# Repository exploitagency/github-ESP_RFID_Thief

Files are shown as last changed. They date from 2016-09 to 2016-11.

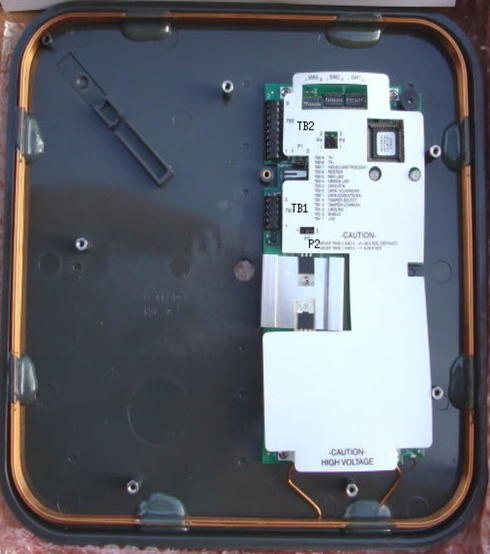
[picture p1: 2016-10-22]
Reference Material/Schematic/5375.jpg

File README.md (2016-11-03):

# ESP_RFID_Thief
Port/Remix by Corey Harding from http://www.LegacySecurityGroup.com<br><br>
This is a port/remix of the Tastic RFID Thief to the Adafruit Feather HUZZAH, an ESP12E chip from the ESP8266 family.  It adds WiFi capability and makes the build nearly plug and play.  There is no SD card as there is a File System library FS.h being utilized and the board has an integrated battery and charging circuit along with WiFi.  One of the benefits of adding WiFi is that now you can remotely view your captures from any standard browser either through the built in access point or by having the ESP_RFID_Thief connect to an existing WiFi network/WiFi-cellular hot spot.  The ESP_RFID_Thief can now play a larger role during penetration testing in a Red Team scenario.  One team member can walk around with the device capturing tags or plant the device while other team members view the capture log.  This way the captured tags can be cloned off site and used by another team member walking in or sent via a network to a tag emulator that the field team member is carrying to avoid looking suspicious by not making the field team member view the logs and manually clone/emulate the card.

<br>
<b>Software used:</b><br>
Arduino IDE: Arduino IDE 1.6.11<br>
Board Manager/Libraries: esp8266 by ESP8266 Community version 2.3.0<br>
<br>
<b>Parts list:</b><br>
HID MaxiProx 5375<br>
Adafruit Feather HUZZAH<br>
2000mah 3.7V Adafruit LiPo Battery<br>
8xAA Battery Holder in Series(12V)<br>
Wire<br>
Solder and Iron<br><br>
<b>Construction:</b><br>
Set voltage jumper on 5375 to 12V.<br>
Optionally disable the beeper(SW1-4).<br>
Insert and screw down red wire from 12V Battery Pack to Positive(+) terminal on the 5375.<br>
Insert and screw down black wire from 12V Battery Pack to Negative(-) terminal on the 5375.<br>
Solder green wire from Data0(Data) to Pin 4 on Feather HUZZAH.<br>
Solder white wire from Data1(Clock) to Pin 5 on Feather HUZZAH.<br>
Solder a wire from GND on the Feather HUZZAH to the GND on the 5375.(Do NOT do the same for Positive)<br>
Attach Lipo Battery to Feather HUZZAH.<br>
Warning: The GPIO Pins on the Feather Huzzah are not supposed to be 5v tolerant(they operate at 3.3v) but this setup has been working fine for me on a breadboard with the 5375 reader powered by 8xAA Batteries. It is recommended to use a level shifter between the Data0/Data1 lines coming from the 5375 and Pins 4/5 on the Feather Huzzah.<br>

<b>Program:</b><br>
Optionally set the ssid and password of the access point being created by the Feather HUZZAH in the sketch source code(.ino file) as well as some other variables such as hidden ssid or IP address.  Or you can even edit the source to make it connect directly to your own network as a client vs being set up as an access point.  I made it easy to set in the source.<br>
Open Current Version Arduino IDE and Install the Library and Board via Board Manager using this link:<br>http://arduino.esp8266.com/stable/package_esp8266com_index.json <br>
Setup the proper board.<br>
Load sketch.<br>
Program.<br>

<b>Access:</b><br>
The Feather HUZZAH has created its own Access Point named "Exploit".<br>
By default the ssid is hidden.<br>
Connect to SSID: "Exploit" WPA2-PASSWORD: "DotAgency"<br>
Wait 90 seconds... while the SPIFFS file system is formatted for the first time.<br>
Open a web browser and connect to the IP address.  Default is http://192.168.1.1 <br>
You can now start scanning cards and view your captures at /log<br>

<b>LEGAL:</b><br>
Obey any international, federal, state, or local laws in your area.<br>
I ported/remixed the Tastic RFID Thief to the Feather HUZZAH for the purpose of proof of concept and legal white hat penetration testing.<br>
I can not and will not be held responsible for the use or misuse of this device.  It is solely up to you to make your own decisions.<br>

That was easy, huh?

Special thanks to Bishop Fox for releasing the original Tastic RFID Thief.<br>
Without them I wouldn't have had the inspiration or motivation to create a tool like this, let alone the code for decoding the Wiegand data.<br>
I hope this build inspires other people to port and remix more projects from the Arduino family over to the ESP8266 devices.<br>

Stay Legal!<br>
-Exploit.Agency

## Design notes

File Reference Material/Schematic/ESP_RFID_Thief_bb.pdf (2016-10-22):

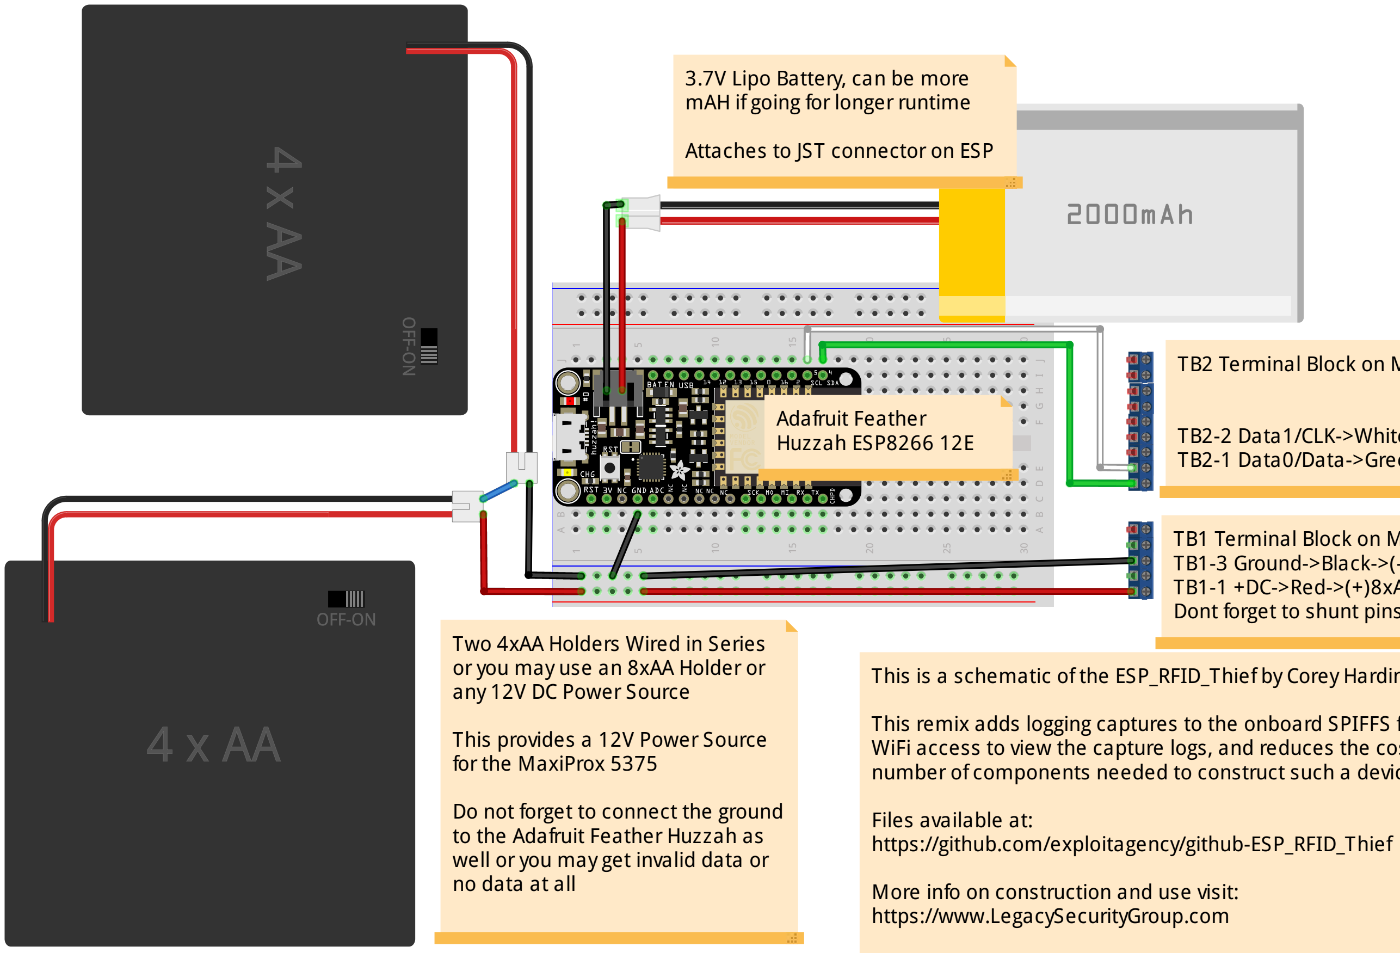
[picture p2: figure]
Two 4xAA Holders Wired in Series or you may use an 8xAA Holder or any 12V DC Power Source; This provides a 12V Power Source forthe MaxiProx 5375; Do not forget to connect the ground to the Adafruit Feather Huzzah as well or you may get invalid data or no data at all; Adafruit Feather Huzzah ESP8266 12E; 3.7V Lipo Battery, can be more mAH if going forlongerruntime; Attaches to JST connector on ESP; Files available at: https://github.com/exploitagency/github-ESP_RFID_Thief; https://www.LegacySecurityGroup.com
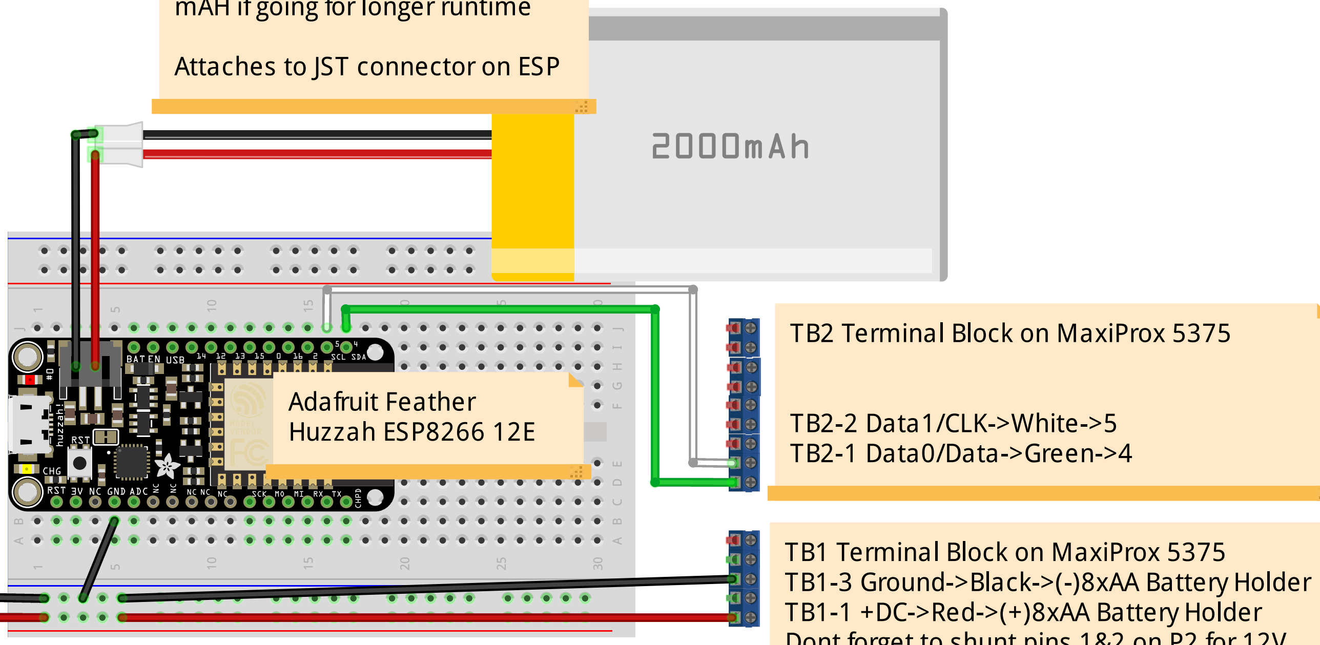
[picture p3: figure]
TB2 Terminal Block on MaxiProx 5375; TB2-2 Data1/CLK->White->5 TB2-1 Data0/Data->Green->4; TB1 Terminal Block on MaxiProx 5375 TB1-3 Ground->Black->(-)8xAA Battery Holder TB1-1 +DC->Red->(+)8xAA Battery Holder

Dont forget to shunt pins 1&2 on P2 for 12V

This is a schematic of the ESP_RFID_Thief by Corey Harding

This remix adds logging captures to the onboard SPIFFS file system, WiFi access to view the capture logs, and reduces the cost and number of components needed to construct such a device

More info on construction and use visit:

Original Tastic RFID Thief is by Bishop Fox

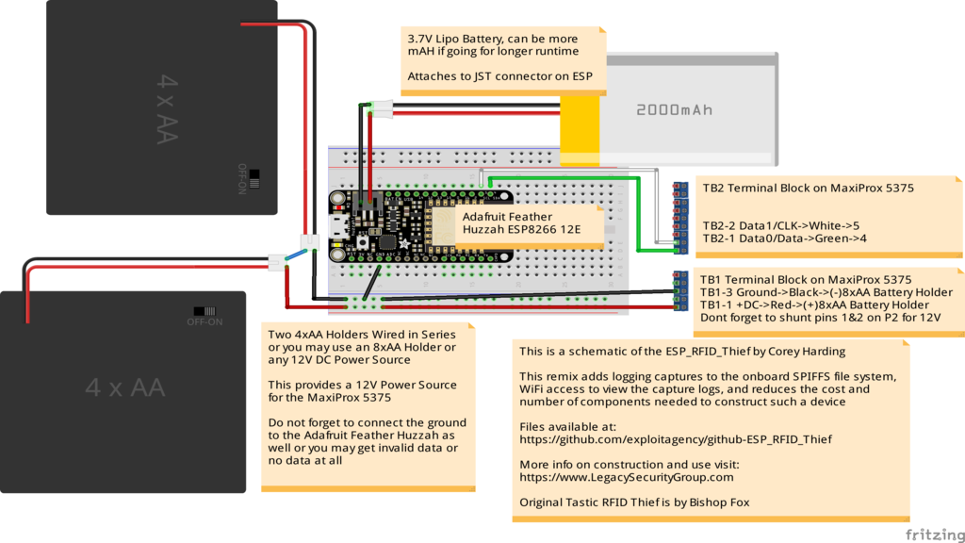
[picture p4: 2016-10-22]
Reference Material/Schematic/ESP_RFID_Thief_bb.png

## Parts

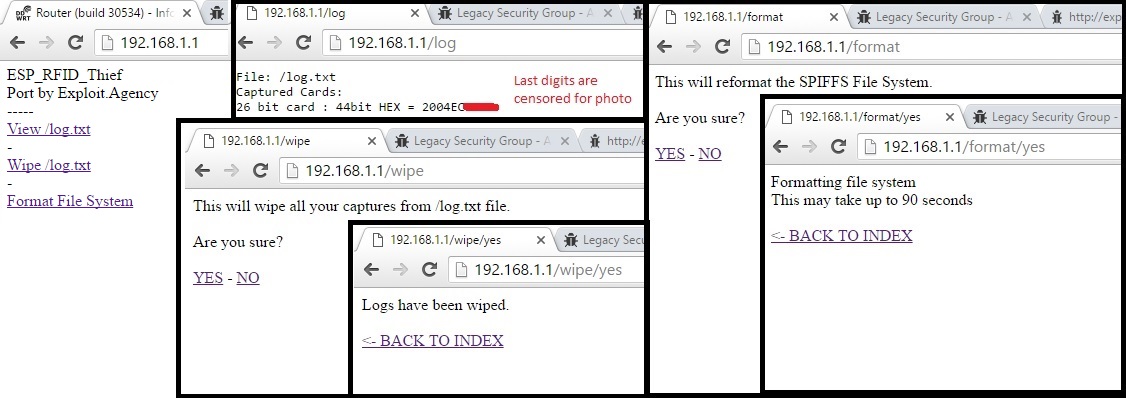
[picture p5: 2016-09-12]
Reference Material/webinterface.jpg

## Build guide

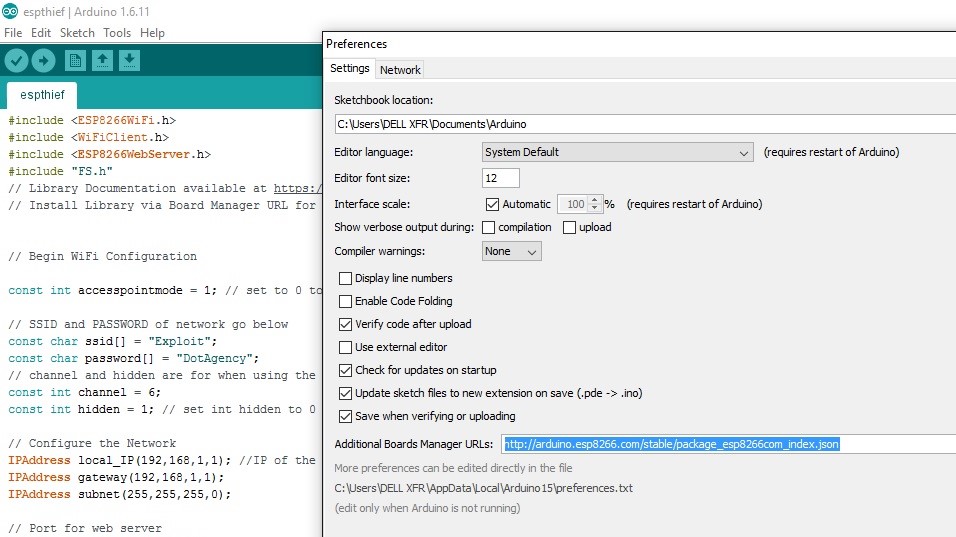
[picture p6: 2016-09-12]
Reference Material/IDE Setup Reference/preferences.jpg

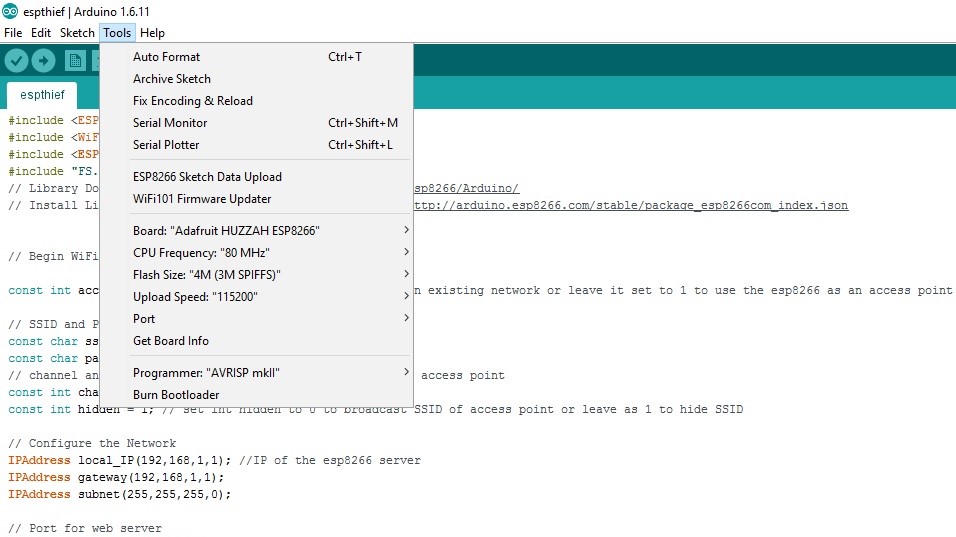
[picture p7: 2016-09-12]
Reference Material/IDE Setup Reference/settings.jpg

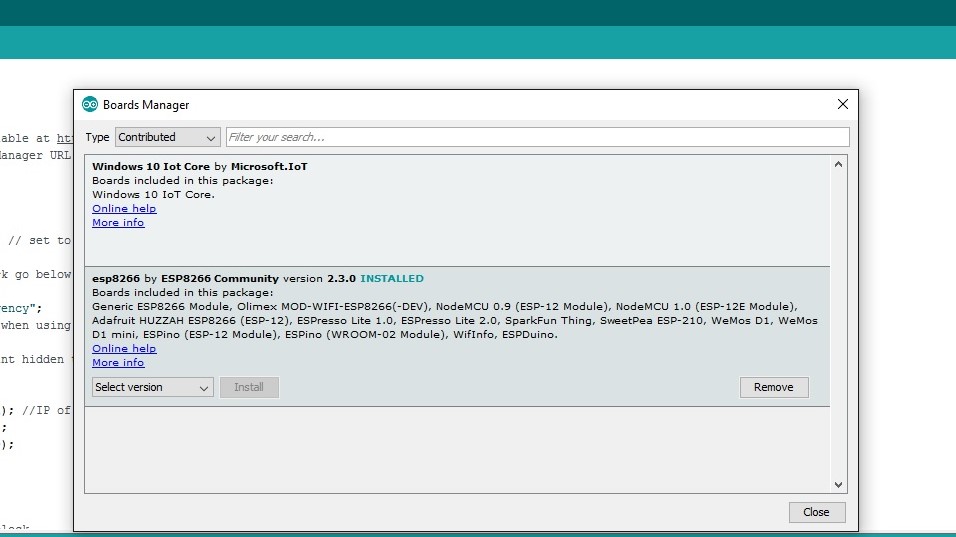
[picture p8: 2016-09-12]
Reference Material/IDE Setup Reference/install boards.jpg

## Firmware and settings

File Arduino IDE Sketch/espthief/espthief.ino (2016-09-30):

#include <ESP8266WiFi.h>
#include <WiFiClient.h>
#include <ESP8266WebServer.h>
#include <FS.h>
// Library Documentation available at https://github.com/esp8266/Arduino/
// Install Library via Board Manager URL for Arduino IDE http://arduino.esp8266.com/stable/package_esp8266com_index.json
// Tastic RFID Thief Originally by Bishop Fox https://www.bishopfox.com/resources/tools/rfid-hacking/
// Remix of Code and Port to ESP8266 by Corey Harding from LegacySecurityGroup - https://www.legacysecuritygroup.com/ http://www.exploit.agency/


// Begin WiFi Configuration

const int accesspointmode = 1; // set to 0 to connect to an existing network or leave it set to 1 to use the esp8266 as an access point

// SSID and PASSWORD of network go below
const char ssid[] = "Exploit";
const char password[] = "DotAgency";
// channel and hidden are for when using the esp8266 as an access point
const int channel = 6;
const int hidden = 1; // set int hidden to 0 to broadcast SSID of access point or leave as 1 to hide SSID

// Configure the Network
IPAddress local_IP(192,168,1,1); //IP of the esp8266 server
IPAddress gateway(192,168,1,1);
IPAddress subnet(255,255,255,0);

// Port for web server
ESP8266WebServer server(80);

// End of WiFi Configuration block


// Begin RFID Thief Config


#define MAX_BITS 100                 // max number of bits 
#define WEIGAND_WAIT_TIME  3000      // time to wait for another weigand pulse.  


unsigned char databits[MAX_BITS];    // stores all of the data bits
volatile unsigned int bitCount = 0;
unsigned char flagDone;              // goes low when data is currently being captured
unsigned int weigand_counter;        // countdown until we assume there are no more bits

volatile unsigned long facilityCode=0;        // decoded facility code
volatile unsigned long cardCode=0;            // decoded card code

// Breaking up card value into 2 chunks to create 10 char HEX value
volatile unsigned long bitHolder1 = 0;
volatile unsigned long bitHolder2 = 0;
volatile unsigned long cardChunk1 = 0;
volatile unsigned long cardChunk2 = 0;


///////////////////////////////////////////////////////
// Process interrupts

// interrupt that happens when INTO goes low (0 bit)
void ISR_INT0()
{
  //Serial.print("0");
  bitCount++;
  flagDone = 0;
  
  if(bitCount < 23) {
      bitHolder1 = bitHolder1 << 1;
  }
  else {
      bitHolder2 = bitHolder2 << 1;
  }
    
  weigand_counter = WEIGAND_WAIT_TIME;  
  
}

// interrupt that happens when INT1 goes low (1 bit)
void ISR_INT1()
{
  //Serial.print("1");
  bitCount++;
  flagDone = 0;
  
   if(bitCount < 23) {
      bitHolder1 = bitHolder1 << 1;
      bitHolder1 |= 1;
   }
   else {
     bitHolder2 = bitHolder2 << 1;
     bitHolder2 |= 1;
   }
  
  weigand_counter = WEIGAND_WAIT_TIME;  
}
// End RFID Thief Config

// Dish out Root Web Page
void handle_root() {
  server.send(200, "text/html", "<html><body>ESP_RFID_Thief<br>A Tastic RFID Thief Port/Remix by:<br>Corey Harding from www.LegacySecurityGroup.com<br>-----<br><a href=\"/log\">View /log.txt</a></html><br>-<br><a href=\"/wipe\">Wipe /log.txt</a><br>-<br><a href=\"/format\">Format File System</a></html>");
}
String webString="";
// End of Dish


// Start Networking
void setup()
{
  Serial.begin(9600);
  Serial.println();

// Determine if set to Access point mode
  if (accesspointmode == 1) {
    Serial.print("Setting up Network Configuration ... ");
    Serial.println(WiFi.softAPConfig(local_IP, gateway, subnet) ? "Success" : "Failed!");

    Serial.print("Starting Access Point ... ");
    Serial.println(WiFi.softAP(ssid, password, channel, hidden) ? "Success" : "Failed!");

    Serial.print("IP address = ");
    Serial.println(WiFi.softAPIP());
  }
// or Join existing network
  else if (accesspointmode != 1) {
    Serial.print("Setting up Network Configuration ... ");
    Serial.println(WiFi.config(local_IP, gateway, subnet) ? "Success" : "Failed!");

    Serial.print("Connecting to network ... ");
    Serial.println(WiFi.begin(ssid, password) ? "Success" : "Failed!");

    Serial.print("IP address = ");
    Serial.println(WiFi.localIP());
  }


// Initialize file system and log file
  SPIFFS.begin();
  // this opens the file "log.txt" in read-mode
  File f = SPIFFS.open("/log.txt", "r");
  
  if (!f) {
    Serial.println("File doesn't exist yet. Creating it");
    // open the file in write mode
    File f = SPIFFS.open("/log.txt", "w");
    if (!f) {
      Serial.println("File creation failed!");
    }
    f.println("File: /log.txt");
    f.println("Captured Cards:");
  }
  f.close();
// End file system block
    
// Begin Web Pages
  server.on("/", handle_root);
  
  server.on("/log", [](){
    webString="";
    File f = SPIFFS.open("/log.txt", "r");
    String webString = f.readString();
    f.close();
    server.send(200, "text/plain", webString);
    Serial.println(webString);
    webString="";
  });

  server.on("/wipe", [](){
    server.send(200, "text/html", "<html><body>This will wipe all your captures from /log.txt file.<br><br>Are you sure?<br><br><a href=\"/wipe/yes\">YES</a> - <a href=\"/\">NO</a></html>");
  });

  server.on("/wipe/yes", [](){
    server.send(200, "text/html", "Logs have been wiped.<br><br><a href=\"/\"><- BACK TO INDEX</a>");
    File f = SPIFFS.open("/log.txt", "w");
    f.println("File: /log.txt");
    f.println("Captured Cards:");
    f.close();
    Serial.println("Logs wiped");
  });

  server.on("/format", [](){
    server.send(200, "text/html", "<html><body>This will reformat the SPIFFS File System.<br><br>Are you sure?<br><br><a href=\"/format/yes\">YES</a> - <a href=\"/\">NO</a></html></html>");
  });

  server.on("/format/yes", [](){
    server.send(200, "text/html", "Formatting file system<br>This may take up to 90 seconds<br><br><a href=\"/\"><- BACK TO INDEX</a>");
    Serial.print("Formatting file system...");
    SPIFFS.format();
    Serial.println(" Success");
  });

  server.on("/easteregg", [](){
    webString="";
    File f = SPIFFS.open("/ee.ee", "r");
    String webString = f.readString();
    f.close();
    server.send(200, "text/plain", webString);
    webString="";
  });

  server.begin();
  Serial.println("HTTP Server Started");
// End of Web Pages

//Start RFID Reader

  pinMode(0, OUTPUT);  // LED
  pinMode(4, INPUT);     // DATA0 (INT0)
  pinMode(5, INPUT);     // DATA1 (INT1)
  
  Serial.println("RFID Reader Started");
  
  // binds the ISR functions to the falling edge of INTO and INT1
  attachInterrupt(4, ISR_INT0, FALLING);  
  attachInterrupt(5, ISR_INT1, FALLING);

  weigand_counter = WEIGAND_WAIT_TIME;
}
//

//Do It!

///////////////////////////////////////////////////////
// LOOP function
void loop()
{

  // This waits to make sure that there have been no more data pulses before processing data
  if (!flagDone) {    

    if (--weigand_counter == 0)
      flagDone = 1;  

  }
  
  // if we have bits and we the weigand counter went out
  if (bitCount > 0 && flagDone) {
    unsigned char i;
    
    getCardValues();
    getCardNumAndSiteCode();
       
    printBits();

     // cleanup and get ready for the next card
     bitCount = 0; facilityCode = 0; cardCode = 0;
     bitHolder1 = 0; bitHolder2 = 0;
     cardChunk1 = 0; cardChunk2 = 0;
     
     for (i=0; i<MAX_BITS; i++) 
     {
       databits[i] = 0;
     }
  }
  
  // Check if someone is requesting a Web Page
  server.handleClient();

}

///////////////////////////////////////////////////////
// PRINTBITS function
void printBits()
{
      
      // open the file in append mode
      File f = SPIFFS.open("/log.txt", "a");
      f.print(bitCount);
      f.print(" bit card : ");
      //f.print(facilityCode);
      //f.print(" : ");
      //f.print(cardCode);
      //f.print(" : ");
      f.print("HEX = ");
      f.print(cardChunk1, HEX);
      f.println(cardChunk2, HEX);
      f.close();

      Serial.print(bitCount);
      Serial.print(" bit card : ");
      //Serial.print("FC = ");
      //Serial.print(facilityCode, HEX);
      //Serial.print(", CC = ");
      //Serial.print(cardCode, HEX);
      Serial.print(", HEX = ");
      Serial.print(cardChunk1, HEX);
      Serial.println(cardChunk2, HEX);

}


///////////////////////////////////////////////////////
// SETUP function
void getCardNumAndSiteCode()
{
     unsigned char i;
  
    // we will decode the bits differently depending on how many bits we have
    // see www.pagemac.com/azure/data_formats.php for more info
    // also specifically: www.brivo.com/app/static_data/js/calculate.js
    switch (bitCount) {

      
    ///////////////////////////////////////
    // standard 26 bit format
    // facility code = bits 2 to 9  
    case 26:
      for (i=1; i<9; i++)
      {
         facilityCode <<=1;
         facilityCode |= databits[i];
      }
      
      // card code = bits 10 to 23
      for (i=9; i<25; i++)
      {
         cardCode <<=1;
         cardCode |= databits[i];
      }
      break;

    ///////////////////////////////////////
    // 33 bit HID Generic    
    case 33:  
      for (i=1; i<8; i++)
      {
         facilityCode <<=1;
         facilityCode |= databits[i];
      }
      
      // card code
      for (i=8; i<32; i++)
      {
         cardCode <<=1;
         cardCode |= databits[i];
      }    
      break;

    ///////////////////////////////////////
    // 34 bit HID Generic 
    case 34:  
      for (i=1; i<17; i++)
      {
         facilityCode <<=1;
         facilityCode |= databits[i];
      }
      
      // card code
      for (i=17; i<33; i++)
      {
         cardCode <<=1;
         cardCode |= databits[i];
      }    
      break;
 
    ///////////////////////////////////////
    // 35 bit HID Corporate 1000 format
    // facility code = bits 2 to 14     
    case 35:  
      for (i=2; i<14; i++)
      {
         facilityCode <<=1;
         facilityCode |= databits[i];
      }
      
      // card code = bits 15 to 34
      for (i=14; i<34; i++)
      {
         cardCode <<=1;
         cardCode |= databits[i];
      }    
      break;

    }
    return;
  
}


//////////////////////////////////////
// Function to append the card value (bitHolder1 and bitHolder2) to the necessary array then tranlate that to
// the two chunks for the card value that will be output
void getCardValues() {
  switch (bitCount) {
    case 26:
        // Example of full card value
        // |>   preamble   <| |>   Actual card value   <|
        // 000000100000000001 11 111000100000100100111000
        // |> write to chunk1 <| |>  write to chunk2   <|
        
       for(int i = 19; i >= 0; i--) {
          if(i == 13 || i == 2){
            bitWrite(cardChunk1, i, 1); // Write preamble 1's to the 13th and 2nd bits
          }
          else if(i > 2) {
            bitWrite(cardChunk1, i, 0); // Write preamble 0's to all other bits above 1
          }
          else {
            bitWrite(cardChunk1, i, bitRead(bitHolder1, i + 20)); // Write remaining bits to cardChunk1 from bitHolder1
          }
          if(i < 20) {
            bitWrite(cardChunk2, i + 4, bitRead(bitHolder1, i)); // Write the remaining bits of bitHolder1 to cardChunk2
          }
          if(i < 4) {
            bitWrite(cardChunk2, i, bitRead(bitHolder2, i)); // Write the remaining bit of cardChunk2 with bitHolder2 bits
          }
        }
        break;

    case 27:
       for(int i = 19; i >= 0; i--) {
          if(i == 13 || i == 3){
            bitWrite(cardChunk1, i, 1);
          }
          else if(i > 3) {
            bitWrite(cardChunk1, i, 0);
          }
          else {
            bitWrite(cardChunk1, i, bitRead(bitHolder1, i + 19));
          }
          if(i < 19) {
            bitWrite(cardChunk2, i + 5, bitRead(bitHolder1, i));
          }
          if(i < 5) {
            bitWrite(cardChunk2, i, bitRead(bitHolder2, i));
          }
        }
        break;

    case 28:
       for(int i = 19; i >= 0; i--) {
          if(i == 13 || i == 4){
            bitWrite(cardChunk1, i, 1);
          }
          else if(i > 4) {
            bitWrite(cardChunk1, i, 0);
          }
          else {
            bitWrite(cardChunk1, i, bitRead(bitHolder1, i + 18));
          }
          if(i < 18) {
            bitWrite(cardChunk2, i + 6, bitRead(bitHolder1, i));
          }
          if(i < 6) {
            bitWrite(cardChunk2, i, bitRead(bitHolder2, i));
          }
        }
        break;

    case 29:
       for(int i = 19; i >= 0; i--) {
          if(i == 13 || i == 5){
            bitWrite(cardChunk1, i, 1);
          }
          else if(i > 5) {
            bitWrite(cardChunk1, i, 0);
          }
          else {
            bitWrite(cardChunk1, i, bitRead(bitHolder1, i + 17));
          }
          if(i < 17) {
            bitWrite(cardChunk2, i + 7, bitRead(bitHolder1, i));
          }
          if(i < 7) {
            bitWrite(cardChunk2, i, bitRead(bitHolder2, i));
          }
        }
        break;

    case 30:
       for(int i = 19; i >= 0; i--) {
          if(i == 13 || i == 6){
            bitWrite(cardChunk1, i, 1);
          }
          else if(i > 6) {
            bitWrite(cardChunk1, i, 0);
          }
          else {
            bitWrite(cardChunk1, i, bitRead(bitHolder1, i + 16));
          }
          if(i < 16) {
            bitWrite(cardChunk2, i + 8, bitRead(bitHolder1, i));
          }
          if(i < 8) {
            bitWrite(cardChunk2, i, bitRead(bitHolder2, i));
          }
        }
        break;

    case 31:
       for(int i = 19; i >= 0; i--) {
          if(i == 13 || i == 7){
            bitWrite(cardChunk1, i, 1);
          }
          else if(i > 7) {
            bitWrite(cardChunk1, i, 0);
          }
          else {
            bitWrite(cardChunk1, i, bitRead(bitHolder1, i + 15));
          }
          if(i < 15) {
            bitWrite(cardChunk2, i + 9, bitRead(bitHolder1, i));
          }
          if(i < 9) {
            bitWrite(cardChunk2, i, bitRead(bitHolder2, i));
          }
        }
        break;

    case 32:
       for(int i = 19; i >= 0; i--) {
          if(i == 13 || i == 8){
            bitWrite(cardChunk1, i, 1);
          }
          else if(i > 8) {
            bitWrite(cardChunk1, i, 0);
          }
          else {
            bitWrite(cardChunk1, i, bitRead(bitHolder1, i + 14));
          }
          if(i < 14) {
            bitWrite(cardChunk2, i + 10, bitRead(bitHolder1, i));
          }
          if(i < 10) {
            bitWrite(cardChunk2, i, bitRead(bitHolder2, i));
          }
        }
        break;

    case 33:
       for(int i = 19; i >= 0; i--) {
          if(i == 13 || i == 9){
            bitWrite(cardChunk1, i, 1);
          }
          else if(i > 9) {
            bitWrite(cardChunk1, i, 0);
          }
          else {
            bitWrite(cardChunk1, i, bitRead(bitHolder1, i + 13));
          }
          if(i < 13) {
            bitWrite(cardChunk2, i + 11, bitRead(bitHolder1, i));
          }
          if(i < 11) {
            bitWrite(cardChunk2, i, bitRead(bitHolder2, i));
          }
        }
        break;

    case 34:
       for(int i = 19; i >= 0; i--) {
          if(i == 13 || i == 10){
            bitWrite(cardChunk1, i, 1);
          }
          else if(i > 10) {
            bitWrite(cardChunk1, i, 0);
          }
          else {
            bitWrite(cardChunk1, i, bitRead(bitHolder1, i + 12));
          }
          if(i < 12) {
            bitWrite(cardChunk2, i + 12, bitRead(bitHolder1, i));
          }
          if(i < 12) {
            bitWrite(cardChunk2, i, bitRead(bitHolder2, i));
          }
        }
        break;

    case 35:        
       for(int i = 19; i >= 0; i--) {
          if(i == 13 || i == 11){
            bitWrite(cardChunk1, i, 1);
          }
          else if(i > 11) {
            bitWrite(cardChunk1, i, 0);
          }
          else {
            bitWrite(cardChunk1, i, bitRead(bitHolder1, i + 11));
          }
          if(i < 11) {
            bitWrite(cardChunk2, i + 13, bitRead(bitHolder1, i));
          }
          if(i < 13) {
            bitWrite(cardChunk2, i, bitRead(bitHolder2, i));
          }
        }
        break;

    case 36:
       for(int i = 19; i >= 0; i--) {
          if(i == 13 || i == 12){
            bitWrite(cardChunk1, i, 1);
          }
          else if(i > 12) {
            bitWrite(cardChunk1, i, 0);
          }
          else {
            bitWrite(cardChunk1, i, bitRead(bitHolder1, i + 10));
          }
          if(i < 10) {
            bitWrite(cardChunk2, i + 14, bitRead(bitHolder1, i));
          }
          if(i < 14) {
            bitWrite(cardChunk2, i, bitRead(bitHolder2, i));
          }
        }
        break;

    case 37:
       for(int i = 19; i >= 0; i--) {
          if(i == 13){
            bitWrite(cardChunk1, i, 0);
          }
          else {
            bitWrite(cardChunk1, i, bitRead(bitHolder1, i + 9));
          }
          if(i < 9) {
            bitWrite(cardChunk2, i + 15, bitRead(bitHolder1, i));
          }
          if(i < 15) {
            bitWrite(cardChunk2, i, bitRead(bitHolder2, i));
          }
        }
        break;
  }
  return;
}
